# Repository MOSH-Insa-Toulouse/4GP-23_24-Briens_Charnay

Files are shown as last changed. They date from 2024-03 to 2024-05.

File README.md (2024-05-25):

# 4GP-23_24-Briens_Charnay

Projet réalisé sur l'année universitaire 2023/2024 de la formation 4GP, dans le cadre de l'Unité de Formation (UF) "du capteur au banc de test".
Le ci-présent fichier README donne tous les éléments de compréhension du projet global, ainsi que de toutes ses composantes. Cela est réalisé de sorte à permettre à l'utilisateur de reprendre tous les fichiers du présent dépôt GitHub, et de s'en servir.

## Sommaire

 - [Introduction](#introduction)
 - [Capteur à base de crayon graphite](#capteur-graphite)
 - [Circuit Electronique Analogique](#circuit-electronique-analogique)
 - [Kicad : réalisation du shield électronique PCB](#kicad)
 - [Banc de test](#banc-de-test)
 - [Interface Homme-Machine](#ihm)
 - [Programmation](#programmation)
 - [Datasheet](#datasheet)
***
## Introduction
### Contexte du projet

Nos travaux se sont basés sur les résultats d'une publication scientifique \[Cheng-Wei Lin et al., 2014]. Celle-ci étudiait l'utilisation de pistes de graphites sur des feuilles de papier comme capteurs de déformation, et donc de contrainte. Une telle technologie aurait de nombreux avantages :
 - Elle est sobre ;
 - Elle consomme peu d'énergie ;
 - Elle est simple d'utilisation ;
 - Elle est facilement réparable et remplaçable avec peu de ressources ;
 - Les ressources nécessaires sont disponibles au grand public pour un prix très réduit.

Du point de vue physique, la technologie se base sur les effets granulaires des couches de graphite déposées sur le papier : qui agissent comme des îlots conducteurs, séparés par une absence de graphite - non conductrice. Cela induit d'infimes capacités en très grand nombre. Lorsque le papier est déformé, la distance entre ces îlots varie, les capacités également. Cela se mesure sur la résistance du dispositif : dont l'évolution angulaire absolue varie linéairement.

### Contenu du projet

Comme annoncé par le nom de l'UF, notre projet a inclut toutes les étapes allant du capteur au bac de test, le tout en open source hardware. Les différentes phases clés du projet ont donc été, telles qu'annoncées en sommaire :
- le développement du capteur à jauge de contrainte à base de crayon graphite ;
- la conception d'un circuit analogique pour interfacer le capteur à jauge de contrainte;
- la programmation arduino de microcontrôleurs ;
- la réalisation d'une application android ;
- la réalisation d'un shield électronique PCB dédié à l'interface du capteur de contrainte ;
- la réalisation d'un banc de test.

Ces différentes étapes ne seront pas présentées dans un ordre temporel mais logique : de sorte à permettre pour chacune de comprendre l'intégralité des éléments.
***
## Capteur graphite
Le capteur graphite développé se présente sous la forme suivante, toutes les grandeurs sont données en mm :



On note le signal prévu pour chacun des pins :
- pin 1 : +5V
- pin 2 : sortie analogique
Les deux pins sont inversibles.

Les zones pointillées doivent être recouverte d'une épaisse couche de graphite, déposée par crayon.
Les pins utilisés sont supposés classiques, comme par exemple des pinces métalliques.
***
## Circuit Electronique Analogique

L'impédance de notre capteur graphite est de l'ordre du gigaOhm, les courants et les variations de courant à mesurer seront donc très faible. Afin que l'entrée convertisseur analogique numérique de l'arduino puisse détecter ces variations de tension, nous avons dû réaliser un circuit d'amplification. Nous avons choisi un montage transimpédance à deux étages en utilisant l'amplificateur opérationnel LTC 1050. Ce montage permet de convertir le courant en tension ainsi que de réaliser un gain conséquent. Le montage final, présenté ci-dessous, inclut aussi plusieurs filtres :

- R5 en entrée protège l'ampli opérationnel contre les décharges électrostatiques, en
forme avec C1 un filtre pour les bruits en tension
- C1 avec R1 forme un filtre pour le bruit en courant
- R2 sera interchangeable, pour permettre une adaptation du calibre
- C4 avec R3 forme un filtre actif
- C2 avec R6 forme le filtre de sortie
- C3 filtre le bruit d'alimentation

LT_Spice_simulation_capteur_commentaires

*Fichier associé* : Circuit_capteur_final.asc

***
## Kicad
La réalisation du shield électronique PCB nous avons utilisé le logiciel Kicad 8.0.

### Schematic

La première étape a été de réaliser le schematic du circuit electronique analogique en implantant les différents composants que nous avons vu dans la partie cirtuit electronique analogique. Nous avons uniquement remplacé le résistance R2 par le potentiomètre digital MCP-41050. Cela nous permet de faire varier la résistance R2 et donc d'avoir la possibilité de jouer sur le gain de l'amplificateur.

Nous avons ajouté plusieurs composants :

- Le capteur graphite
- Un capteur flex dans le but de le comparer avec notre solution lowtech
- Un écran OLED afin d'afficher les valeurs mesurées ainsi que la valeur de résistance du potentiomètre digital.
- Un module bluetooth HC-6 pour pouvoir communiquer avec une application Android
- Des boutons qui permettrons de se déplacer dans le menu et de selectionner un champ
- Le shield pour connecter l'arduino
- Un filtre passif pour les bruits venant de l'alimentation

Kicad_schematic

*Fichier associé* : Shield_capteur.kicad_sch

***
### PCB

Nous avons ensuite pu implanter les différents composants sur le PCB comme présenté ci-dessous.

Kicad_pcb

Les dimensionnements sont les suivants :
- La largeur des pistes est de 0,8mm
- Les pads circulaires pour les composants ont un diamètre de 2,54mm avec un trou circulaire de 0,8mm
- Les pads ovoïde pour les raccordements par pins ont une largeur de 2mm et une longueur de 2,54mm. Les pins de raccordements pour l'arduino nécessite un trou de 1mm de diamètre. Les pads pour les supports de plaques ont quand à eux un trou de 0,8mm

  Le plan de masse a été généré automatiquement par Kicad. En effectuant le test de vérification des règles de dessin, nous avons pu corriger des erreurs de placement ou de superposition des composants.
L'organisation de notre PCB nous a permis de ne pas avoir besoin de créer des VIAs. Nous avons ensuite pu imprimer le masque de notre circuit afin de réaliser le shield par voie chimique.

*Fichier associé* : Shield_capteur.kicad_pcb

***
## Banc de test

Afin de réaliser des mesures précises et reproductibles, nous avons réalisé un banc de test complet. Celui-ci est composé de différents composants présentés ci-dessous :

Banc_de_test

Comme présenté sur la photo détaillée, nous avons utilisé un second arduino pour réaliser notre banc de test. Ce dernier contrôle le servomoteur qui permet l'enroulement d'un cable autour d'une poulie. Cela permet de plier d'un pas choisi, de manière très contrôlé et reproductible le capteur graphite. Ce second arduino est branché sur les pins l'arduino principal afin qu'une synchronisation entre les changements de degrés et la mesure puisse s'effectuer. Vous trouverez plus de détails sur la communication entre les deux arduino dans la partie programmation. 

***
## IHM
L'Interface Homme-Machine (ou IHM) correspond à tous les éléments permettant la communication entre l'utilisateur et les composants software.
### Boutons et écran OLED
Trois boutons ainsi qu'un écran OLED sont directement présents sur le shield :



Du haut vers le bas, les trois boutons correspondent aux actions :
- select ;
- up ;
- down.

L'écran OLED affiche un total de 4 champs. Les deux premiers sont modifiables, les deux derniers correspondent à des mesures réalisées.
- la valeur du potentiomètre digital ;
- l'unité de mesure ;
- la valeur mesurée dans cette unité par le capteur graphite ;
- la valeur mesurée dans cette unité par le Flex Sensor, capteur commercial.

L'utilisateur contrôle un curseur, celui-ci a deux états disponibles : "- xyz -" et "< xyz >". Le premier correspond au choix du champ à modifier : il permet à l'utilisateur de choisir s'il souhait modifier la valeur du potentiomètre ou l'unité de mesure. Le deuxième correspond à la modification du champ actuel : les boutons up et down permettent alors de se déplacer parmis les différentes options proposées pour le champ actuel. La pression du bouton select permet de passer d'un état à l'autre.
### Application Android
Il est également possible de communiquer avec l'arduino via une application android connectée en bluetooth. Celle-ci se présente ainsi :



Chaque ligne possède un rôle :
- la première, "Bluetooth et fichier" : permet de se connecter à l'arduino en bluetooth, de s'en déconnecter, et d'exporter les données du graphe. L'export se fait dans un fichier texte généré dans le téléphone ;
- la deuxième, "Contrôle d'acquisition" : permet de lancer l'acquisition de données, de la stopper, ou de lancer un test automatisé de la jauge (voir banc de test) ;
- la troisième est le graphe sur lequel apparaissent les données récoltées ;
- la quatrième, "Contrôle graphique" : permet de remettre le graphique à zéro, et de changer l'unité de mesure en volts, en ohms, ou en degrés ;
- la cinquième, "Nombre de points" : permet de choisir le nombre de point maximum à enregistrer et afficher sur le graphique.

*Fichiers associés* :
- application android/AppMOSH1.apk
- application android/CodeAppAndroid.aia
***
## Programmation
### Protocoles de communication
Au sein de notre projet, nous avons mis en place deux protocoles de communication : entre le téléphone et l'arduino du capteur graphite (bluetooth), ainsi qu'entre cette dernière et l'arduino du banc de test (électronique directe).
#### Communication Bluetooth
Dans le cadre de la communication bluetooth entre le téléphone et l'arduino du capteur graphite, les données sont transmises sous format ASCII, par des messages de 16 caractères, sous le format suivent :



Le téléphone est maître de la communication, l'arduino joue le rôle d'esclave. Le caractère "commande" permet de transmettre une information ou ordre spécifique, nous notons les différentes possibilités :

Du téléphone vers l'arduino :
- d : demander l'envoie d'un message ;
- V : choix d'une mesure en volts ;
- O : choix d'une mesure en ohms ;
- D : choix d'une mesure en degrés ;
- t : lancement d'un test automatisé.

De l'arduino vers le téléphone :
- V : message contenant une donnée en volts ;
- O : message contenant une donnée en ohms ;
- D : message contenant une donnée en degrés ;
- c : information du lancement d'un test automatisé ;
- f : information de la fin d'un test automatisé.
#### Communication électronique directe
Dans le cadre de la communication électronique directe entre les arduinos du capteur graphite et du banc de test, deux lignes de communication sont utilisées : chacune contrôlée par une carte arduino. Ce protocole de communication permet de synchroniser le lancement des tests automatisés entre le banc de test, et l'enregistrement des mesures sur le téléphone. Le chronogramme se présente ainsi :



Nous détaillons chaque évolution :
- état initial : les deux lignes sont à l'état down ;
- l'arduino du capteur reçoit l'ordre de l'application de lancer le test automatisé, sa ligne passe à up ;
- l'arduino du banc de test lit l'information, lance le test, et passe sa ligne à up ;
- l'arduino du capteur lit que le test a bien été lancé, passe sa ligne à down, et envoie l'information à l'application ;
- une fois le test terminé, l'arduino du banc de test passe sa ligne à down ;
- l'arduino du capteur lit que le test est terminé, et envoie l'information à l'application.
### Programme Arduino
Deux programmes arduinos ont été créés, pour les deux cartes utilisées dans ce projet : celle du shield PCB (connectée au capteur graphite), et celle du banc de test. Nous détaillons leur fonctionnement.
#### Arduino du capteur graphite
Le fonctionnement général de l'arduino du capteur graphite suit la logique présentée dans le schéma suivant :



Le choix a été fait de réaliser un debouncing des boutons entièrement software.

*Fichier associé* : programme_complet/programme_complet.ino
#### Arduino du banc de test
L'arduino du banc de test possède un programme bien plus simple et direct. Celui-ci suit la structure suivante :
- ajuster la position du Servomoteur : à 0 si aucun test n'est en cours, sinon une autre valeur variable ;
- lire et écrire sur les lignes de communication avec l'arduino du capteur graphite.

*Fichier associé* : programme_second_arduino/prog_second_arduino/prog_second_arduino.ino
***
## Datasheet
Finalement, la combinaison de tous ces éléments a permis la récolte de données, et la rédaction d'une datasheet complète du capteur graphite. Celle-ci est divisée en plusieurs catégories :
- Caractéristiques générales : points clés à l'avantage du capteur ;
- Description : description de la physique du fonctionnement du capteur, développement de ses avantages clés, objectif du développement du capteur ;
- Description des pins : description des pins et signaux du capteur, permettant son implémentation électronique ;
- Dimensions : description matérielle du capteur ;
- Spécifications : description technique concise du capteur ;
- Conditions d'utilisation standard : conditions environnementales classiques, pour lesquelles le capteur a été développé ;
- Caractéristiques électriques : pour les différentes variantes du capteur (en fonction du crayon utilisé), évolution de la résistance absolue et relative en fonction de l'angle ;
- Utilisation typique : exemple d'un circuit électronique typique dans lequel implémenter le capteur pour en tirer des données.
Ce circuit électronique typique correspond à celui que nous avons réalisé sur l'arduino du capteur, et présenté précédemment.

Cette datasheet permet à tout nouvel arrivant de produire et d'utiliser notre capteur graphite : dans un esprit Low-Tech et Open Source.

*Fichier associé* : Datasheet_strain_gauge-MCharnay-ABriens.pdf

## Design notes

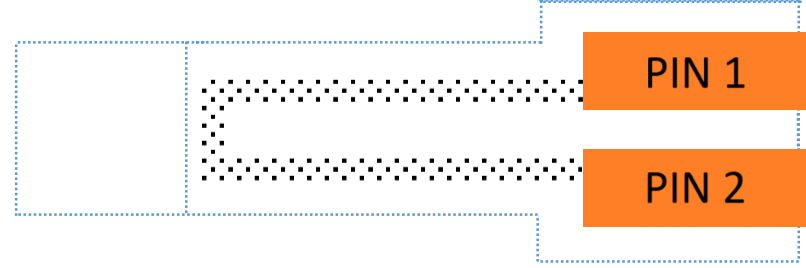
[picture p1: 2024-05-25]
Image_capteur_pins.png

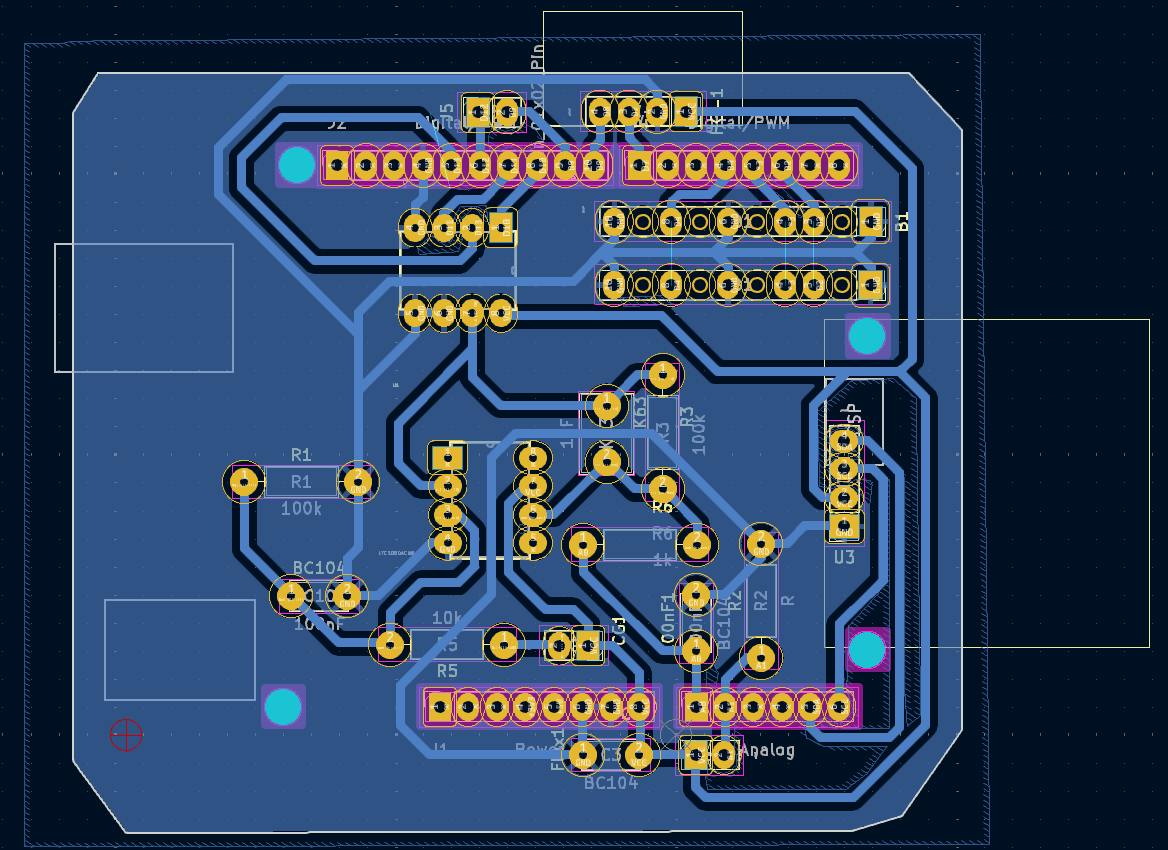
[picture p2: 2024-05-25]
Kicad_pcb.png

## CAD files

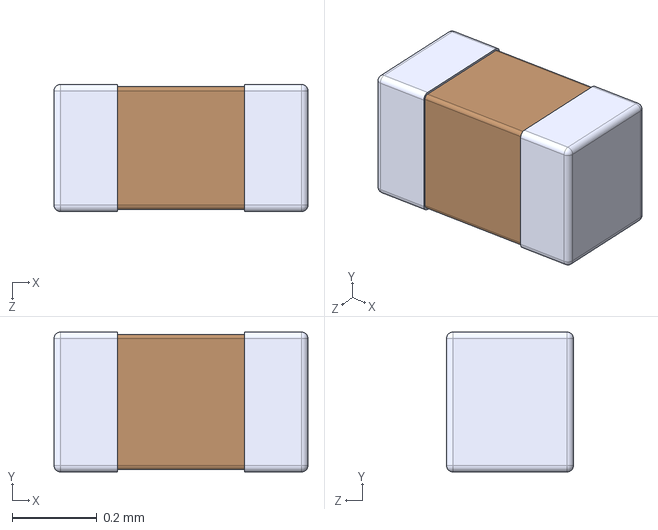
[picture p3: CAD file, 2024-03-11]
BC104_symbol/GRM033B31A104KE84D.step
0.6 x 0.33 x 0.3 mm

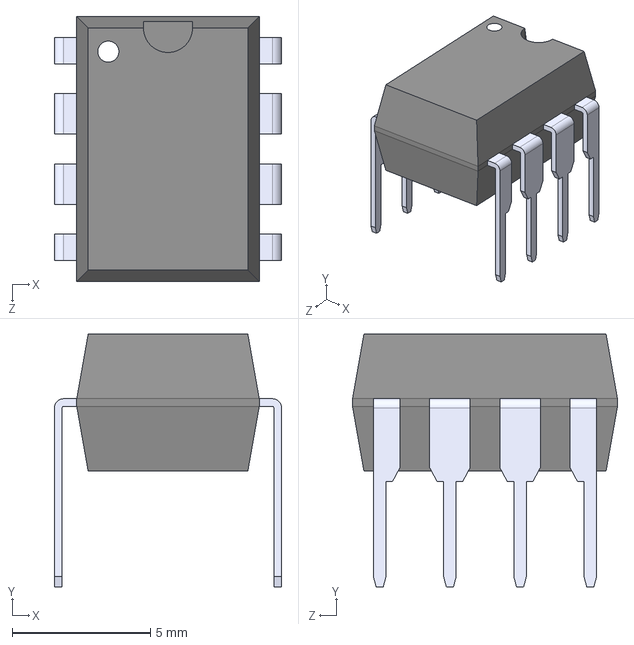
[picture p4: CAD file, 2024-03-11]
LTC1050ACN8_PBF/LTC1050ACN8_PBF.step
8.22 x 9.14 x 9.59 mm

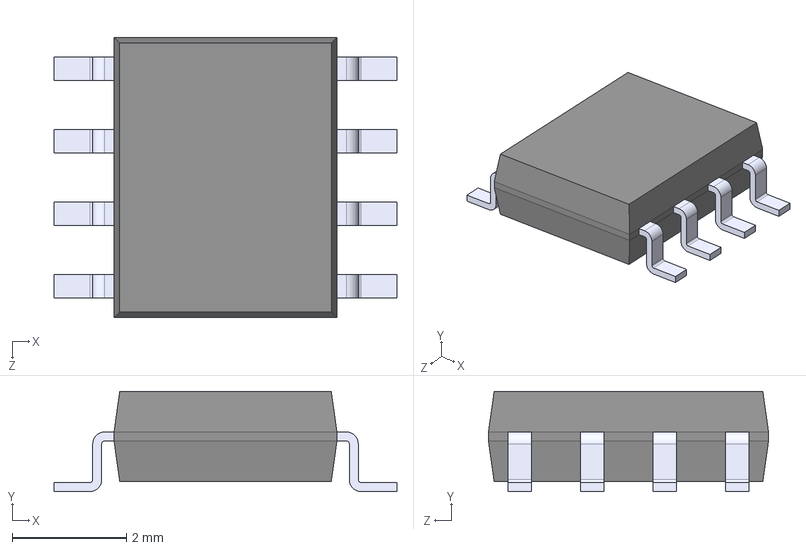
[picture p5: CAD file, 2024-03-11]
MCP4131-103E_SN/MCP4131-103E_SN.step
6.00 x 1.75 x 4.90 mm

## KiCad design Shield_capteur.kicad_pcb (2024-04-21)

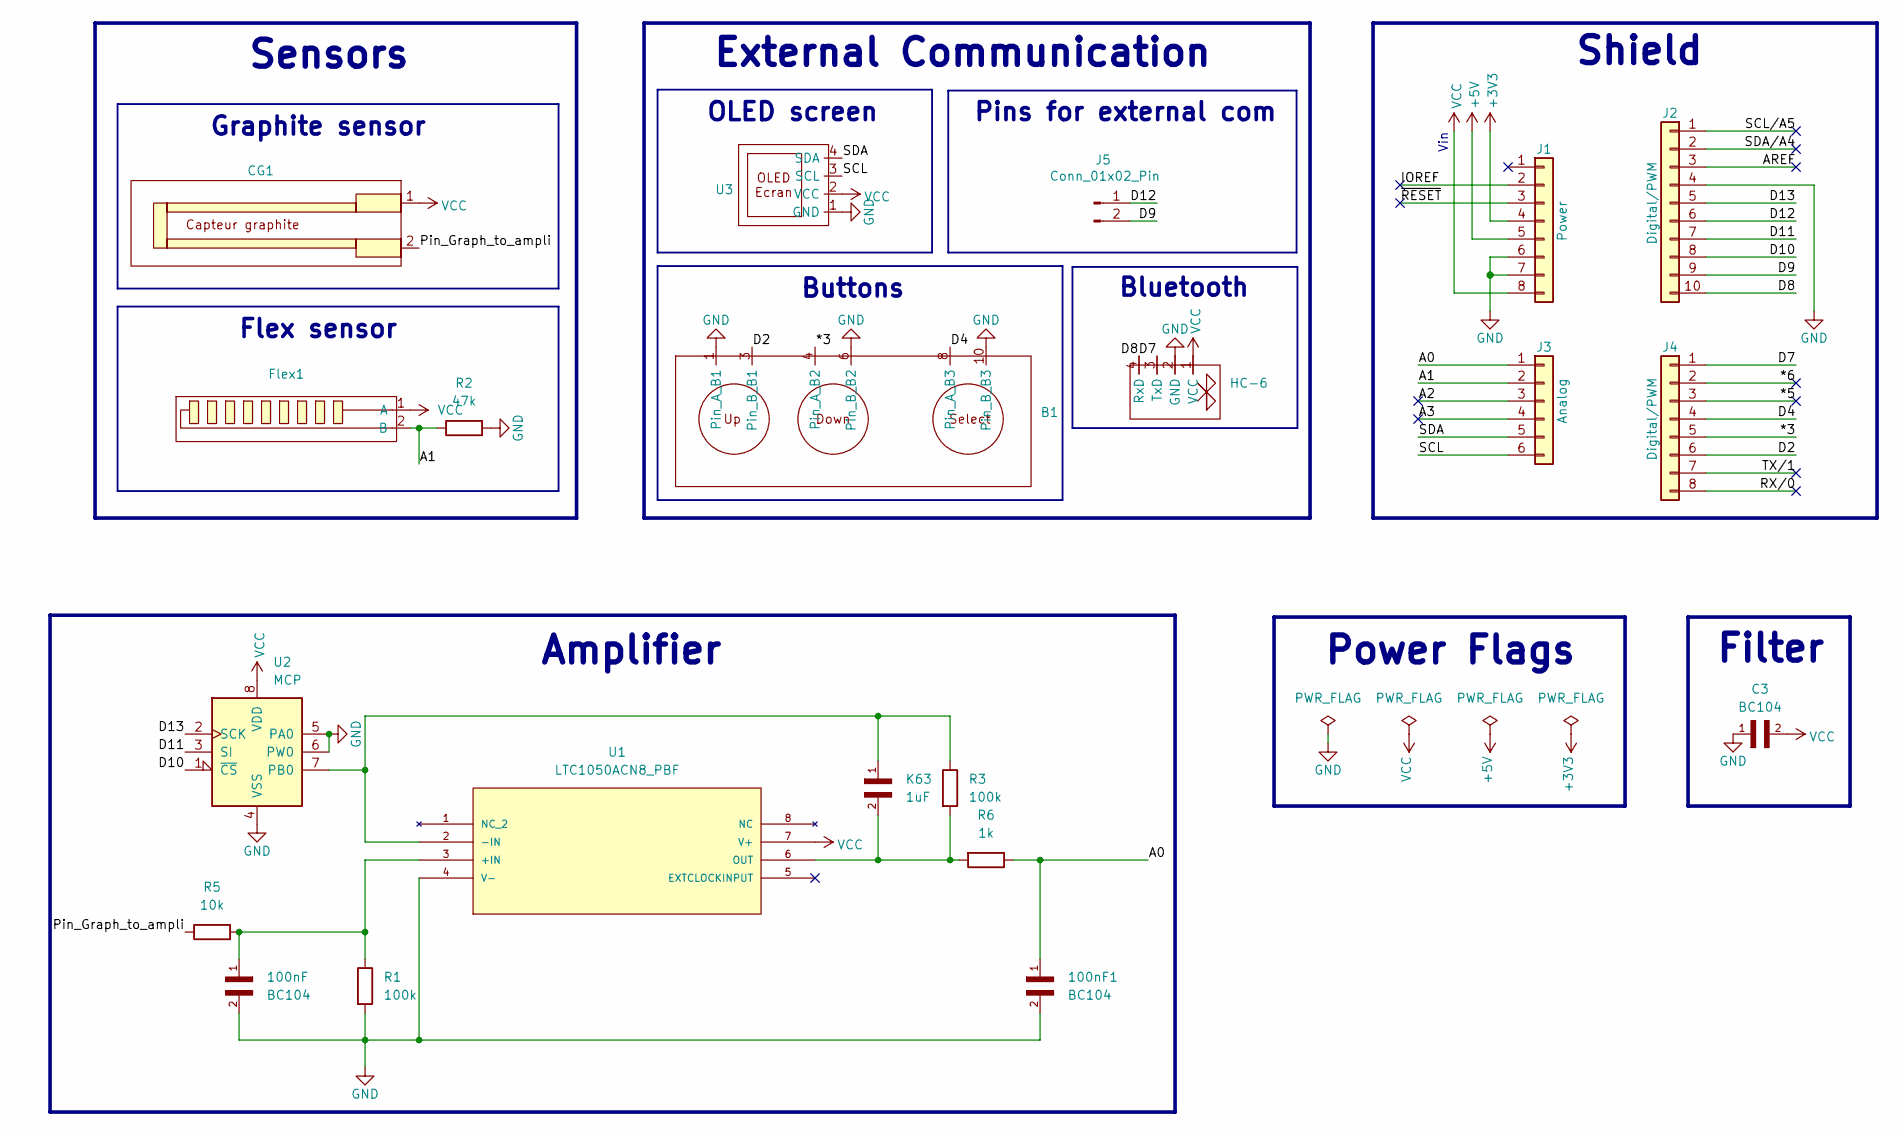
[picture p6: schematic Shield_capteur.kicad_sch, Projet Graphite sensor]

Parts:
100nF1: BC104; C_Disc_D5.0mm_W2.5mm_P5.00mm
B1: Boutons_x3
BC104: 100nF; C_Disc_D5.0mm_W2.5mm_P5.00mm
C3: BC104; C_Disc_D5.0mm_W2.5mm_P5.00mm
CG1: PinSocket_1x02_P2.54mm_Vertical
Flex1: PinSocket_1x02_P2.54mm_Vertical
HC-6: PinSocket_1x04_P2.54mm_Vertical
J1: Power; PinSocket_1x08_P2.54mm_Vertical
J2: Digital/PWM; PinSocket_1x10_P2.54mm_Vertical
J3: Analog; PinSocket_1x06_P2.54mm_Vertical
J4: Digital/PWM; PinSocket_1x08_P2.54mm_Vertical
J5: Conn_01x02_Pin; PinSocket_1x02_P2.54mm_Vertical
K63: 1uF; C_Rect_L7.0mm_W4.5mm_P5.00mm
R1, R3: 100k; R_Axial_DIN0207_L6.3mm_D2.5mm_P10.16mm_Horizontal
R2: 47k; R_Axial_DIN0207_L6.3mm_D2.5mm_P10.16mm_Horizontal
R5: 10k; R_Axial_DIN0207_L6.3mm_D2.5mm_P10.16mm_Horizontal
R6: 1k; R_Axial_DIN0207_L6.3mm_D2.5mm_P10.16mm_Horizontal
U1: LTC1050ACN8_PBF; PDIP-8_N; MANUFACTURER_PART_NUMBER ltc1050acn8
U2: MCP; PDIP-8_N
U3: PinSocket_1x04_P2.54mm_Vertical

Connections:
+3V3: J1.4
+5V: J1.5
/*3: B1.4 (Pin_A_B2), J4.5
/*5: J4.3
/*6: J4.2
/A0: 100nF1.1, J3.1, R6.1
/A1: Flex1.2 (B), J3.2, R2.1
/A2: J3.3
/A3: J3.4
/AREF: J2.3
/D2: B1.3 (Pin_B_B1), J4.6
/D4: B1.8 (Pin_A_B3), J4.4
/D7: HC-6.3 (TxD), J4.1; also elsewhere on the board
/D8: HC-6.4 (RxD), J2.10; also elsewhere on the board
/D9: J2.9, J5.2
/D10: J2.8, U2.1 (~CS)
/D11: J2.7, U2.3 (SI)
/D12: J2.6, J5.1
/D13: J2.5, U2.2 (SCK)
/IOREF: J1.2
/RX/0: J4.8
/SCL: J3.6, U3.3 (SCL)
/SCL/A5: J2.1
/SDA: J3.5, U3.4 (SDA)
/SDA/A4: J2.2
/TX/1: J4.7
/~RESET: J1.3
GND: 100nF1.2, B1.1 (Pin_A_B1), B1.6 (Pin_B_B2), B1.10 (Pin_B_B3), BC104.2, C3.1, HC-6.2 (GND), J1.6, J1.7, J2.4, R1.2, R2.2, U1.4 (V-), U2.4 (VSS), U2.5 (PA0), U2.6 (PW0), U3.1 (GND); also elsewhere on the board
unnamed: CG1.2, R5.1
unnamed: BC104.1, R1.1, R5.2, U1.3 (+IN)
unnamed: K63.1, R3.1, U1.2 (-IN), U2.7 (PB0)
unnamed: K63.2, R3.2, R6.2, U1.6 (OUT)
VCC: C3.2, CG1.1, Flex1.1 (A), HC-6.1 (VCC), J1.8, U1.7 (V+), U2.8 (VDD), U3.2 (VCC); also elsewhere on the board

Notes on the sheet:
Graphite sensor
Vin
Amplifier
Flex sensor
Filter
Power Flags
Pins for external com
Bluetooth
Shield
Sensors
OLED screen
External Communication
Buttons

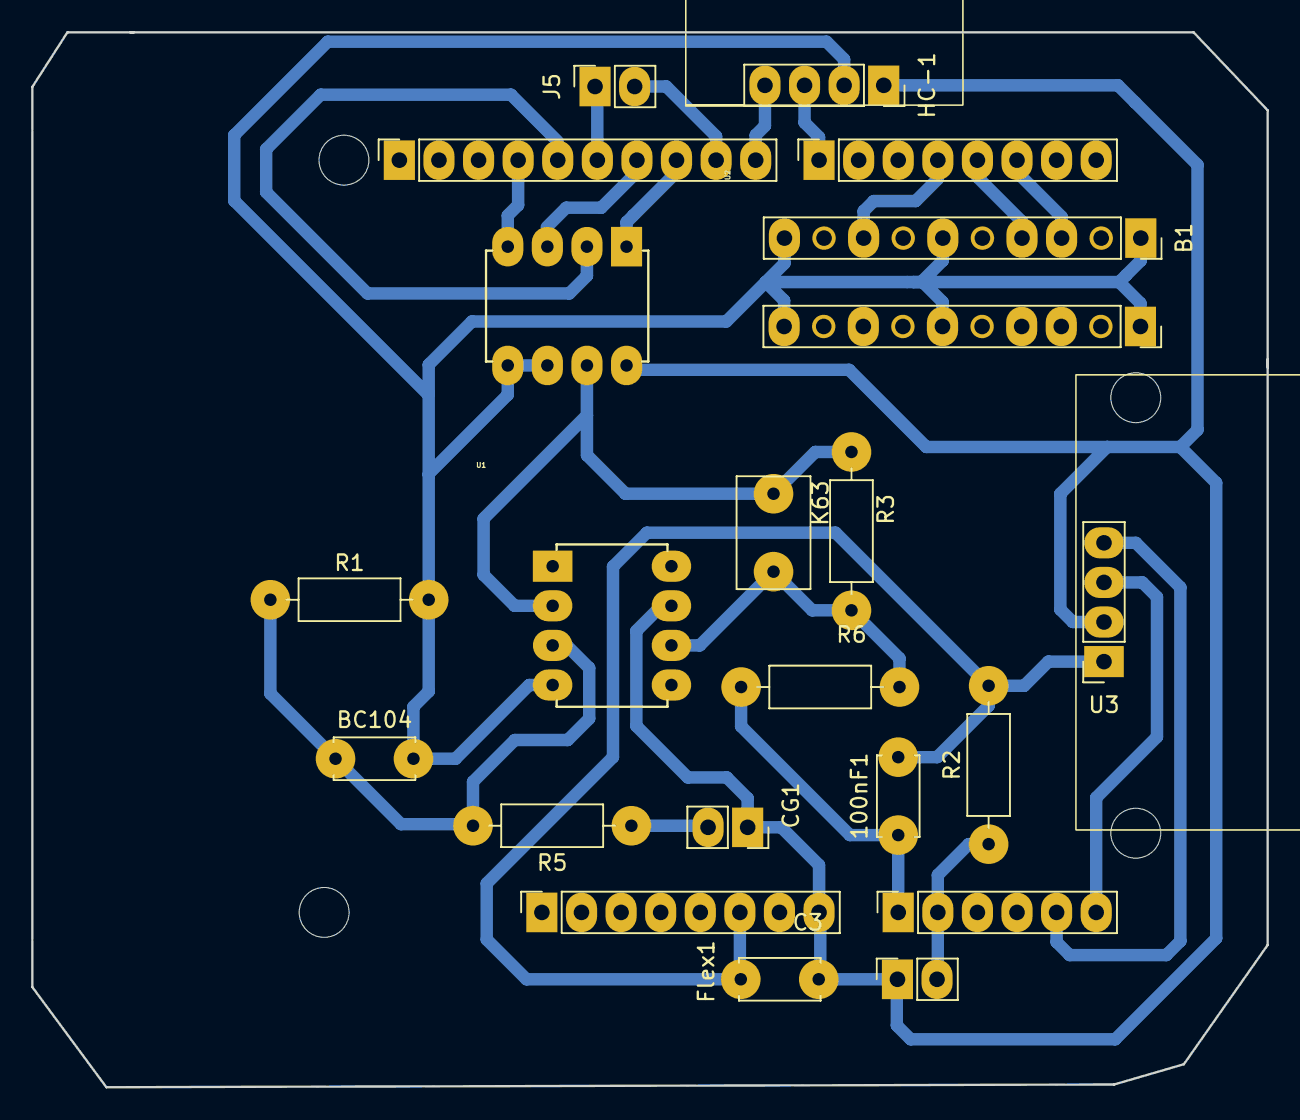
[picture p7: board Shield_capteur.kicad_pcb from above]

Board: 2 copper layers, 79.2 x 67.7 mm, 25 parts (0 on the bottom side), 20 nets.

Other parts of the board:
HC-1: PinSocket_1x04_P2.54mm_Vertical
MH1, MH2, MH3, MH4: MountingHole_3.2mm

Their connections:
/D7: HC-1.3 (TxD); also elsewhere on the board
/D8: HC-1.4 (RxD); also elsewhere on the board
GND: HC-1.2 (GND); also elsewhere on the board
VCC: HC-1.1 (VCC); also elsewhere on the board

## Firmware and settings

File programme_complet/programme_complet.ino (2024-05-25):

#include <SoftwareSerial.h>
#include <Adafruit_SSD1306.h>
#include <SPI.h>
//#include <Servo.h>

//#define pinServo 2
//Servo myservo;

#define flexPin A1
#define flexR_DIV 39000
#define flexflatResistance 25000
#define flexbendResistance 100000

#define bluetoothRxPin 7
#define bluetoothTxPin 8
#define baudrate 9600
#define sizeBuffer 16
SoftwareSerial mySerial(bluetoothRxPin,bluetoothTxPin);
char bufferBluetoothOutput[sizeBuffer]={0};
char bufferBluetoothInput[sizeBuffer]={0};

#define ampliPin A0

#define upButton 3
uint8_t upState;
uint8_t lastUpState=1;
long upTimer;
#define downButton 2
uint8_t downState;
uint8_t lastDownState=1;
long downTimer;
#define selectButton 4
uint8_t selectState;
uint8_t lastSelectState=1;
long selectTimer;
#define debounceDelay 50

#define nombreDePixelsEnLargeur 128         // Taille de l'écran OLED, en pixel, au niveau de sa largeur
#define nombreDePixelsEnHauteur 64          // Taille de l'écran OLED, en pixel, au niveau de sa hauteur
#define brocheResetOLED         -1
#define adresseI2CecranOLED     0x3C
Adafruit_SSD1306 ecranOLED(nombreDePixelsEnLargeur, nombreDePixelsEnHauteur, &Wire, brocheResetOLED);

#define nbOptionsPotar 12
#define nbOptionsUnite 3
const uint32_t tabChoixPotar[nbOptionsPotar]={125,330,730,1130,1930,2530,5100,10020,19920,30600,40600,50300};
uint8_t choixPotar=0;
uint8_t choixUnite=0;
uint8_t positionMenu=0;
uint8_t selection=0;

#define MCP_NOP 0b000000000
#define MCP_WRITE 0b00010001
#define MCP_SHTDWN 0b00100001

const uint8_t ssMCPin = 10;
const int adresseChoixPotar[nbOptionsPotar]={0,1,3,5,9,12,25,50,100,155,205,255};

const uint8_t VCC=5;

#define syncTxPin 12
#define syncRxPin 9
uint8_t syncTx=0;
uint8_t pastRx=0;
uint8_t syncRx=0;

void setup() {
  Serial.begin(baudrate);

  //~~ Flex Sensor ~~//
  pinMode(flexPin,INPUT);

  //~~ Ampli - capteur graphite ~~//
  pinMode(ampliPin,INPUT);

  //~~ Bluetooth ~~//
  pinMode(bluetoothRxPin,INPUT);
  pinMode(bluetoothTxPin,OUTPUT);
  mySerial.begin(baudrate);
  bufferBluetoothOutput[0]='\0';
  bufferBluetoothOutput[sizeBuffer-1]='\0';

  //~~ Boutons ~~//
  pinMode(upButton,INPUT_PULLUP);
  pinMode(downButton,INPUT_PULLUP);
  pinMode(selectButton,INPUT_PULLUP);

  //~~ OLED ~~//
  ecranOLED.begin(SSD1306_SWITCHCAPVCC, adresseI2CecranOLED);

  //~~ Potar digital ~~//
  pinMode(ssMCPin,OUTPUT);
  digitalWrite(ssMCPin,HIGH);
  SPI.begin();

  //~~ Test automatisé ~~//
  pinMode(syncTxPin,OUTPUT);
  pinMode(syncRxPin,INPUT);
}

void loop() {
  //if(choixPotar==4){choixPotar=3;}
  //else{choixPotar=4;}

   //~~~~~~~~~~~~~~~~ Flex Sensor ~~~~~~~~~~~~~~~~//
  int flexVolt=analogRead(flexPin);
  if(flexVolt==0)flexVolt=1;//eviter division par 0 dans la formule suivante
  float flexRes=flexR_DIV*(1023.0/flexVolt-1.0);
  float flexAngle=map(flexRes,flexflatResistance,flexbendResistance,0,90.0);

  //Serial.println("Cadeau, res : "+String(flexRes)+" ; angle : "+String(flexAngle)+"°.");
  
  //~~~~~~~~~~~~~~~~ Ampli - capteur graphite ~~~~~~~~~~~~~~~~//
  int ampliVolt=analogRead(ampliPin);

  //~~~~~~~~~~~~~~~~ Bluetooth ~~~~~~~~~~~~~~~~//
  commBluetooth(bufferBluetoothOutput,bufferBluetoothInput);
  if(bufferBluetoothInput[0]=='d'){//si l'app envoie une demande de "data"
    char unit='V';
    if(choixUnite==1)unit='O';
    if(choixUnite==2)unit='D';
    //un message composé de l'unité et de la mesure est envoyé
    sendMsg(unit,conversionMesure(ampliVolt),4);
  }
  if(bufferBluetoothInput[0]=='V'){
    choixUnite=0;
  }
  if(bufferBluetoothInput[0]=='O'){
    choixUnite=1;
  }
  if(bufferBluetoothInput[0]=='D'){
    choixUnite=2;
  }
  if(bufferBluetoothInput[0]=='t'){
    syncTx=1;
  }
  bufferBluetoothInput[0]='\0';
  
  //~~~~~~~~~~~~~~~~ Boutons ~~~~~~~~~~~~~~~~//
  debouncingButtons();

  //~~~~~~~~~~~~~~~~ OLED ~~~~~~~~~~~~~~~~//
  updateOLED(conversionMesure(ampliVolt),choixMesureFlex(flexVolt,flexRes,flexAngle));
  //Serial.println(ampliVolt);
  /*Serial.print(F("Potentiometre(0-4) : "));
  Serial.print(choixPotar);
  Serial.print(F(" ; Unite(0-2) : "));
  Serial.println(choixUnite);
  Serial.print(F(" ; selection(V/F) : "));
  Serial.print(selection);
  Serial.print(F(" ; positionMenu(0-2) : "));
  Serial.println(positionMenu);*/
  
  //~~~~~~~~~~~~~~~~ Potentiometre digital ~~~~~~~~~~~~~~~~//
  updatePotar();

  //~~~~~~~~~~~~~~~~ Test automatisé ~~~~~~~~~~~~~~~~//
  syncTest();

  //delay(20);
}

void debouncingButtons()
{
  int readUp=digitalRead(upButton);
  int readDown=digitalRead(downButton);
  int readSelect=digitalRead(selectButton);

  if(readUp!=lastUpState){
    upTimer=millis();
    //Serial.println("ici : "+String(millis()));
  }
  if((millis()-upTimer)>debounceDelay){
    if((upState!=readUp)&&!readUp){
      upButtonAction();
      //Serial.println("ACTION UP : "+String(millis()));
    }
    upState=readUp;
  }
  lastUpState=readUp;

  if(readDown!=lastDownState){
    downTimer=millis();
  }
  if((millis()-downTimer)>debounceDelay){
    if((downState!=readDown)&&!readDown){
      downButtonAction();
      //Serial.println("ACTION DOWN : "+String(millis()));
    }
    downState=readDown;
  }
  lastDownState=readDown;

  if(readSelect!=lastSelectState){
    selectTimer=millis();
  }
  if((millis()-selectTimer)>debounceDelay){
    if((selectState!=readSelect)&&!readSelect){
      selectButtonAction();
      //Serial.println("ACTION SELECT : "+String(millis()));
    }
    selectState=readSelect;
  }
  lastSelectState=readSelect;
}

void upButtonAction()
{
  if(selection==0){
    positionMenu=(positionMenu-1+3)%3;
  }
  else{
    if(positionMenu==1){
      choixPotar=(choixPotar+1)%nbOptionsPotar;
    }
    if(positionMenu==2){
      choixUnite=(choixUnite+1)%nbOptionsUnite;
    }
  }
}

void downButtonAction()
{
  if(selection==0){
    positionMenu=(positionMenu+1)%3;
  }
  else{
    if(positionMenu==1){
      choixPotar=(choixPotar-1+nbOptionsPotar)%nbOptionsPotar;
    }
    if(positionMenu==2){
      choixUnite=(choixUnite-1+nbOptionsUnite)%nbOptionsUnite;
    }
  }
}

void selectButtonAction()
{
  if(positionMenu!=0)selection=(selection+1)%2;
}

void commBluetooth(char* bufferOutput, char* bufferInput)
{
  int i=0;
  while(mySerial.available()){
    do{
      bufferInput[i++]=(char)mySerial.read();
      delay(3);
    }while(mySerial.available()>0);
    Serial.println(bufferInput);
  }
  if(bufferOutput[0]!='\0'){
    mySerial.println(bufferOutput);
    bufferOutput[0]='\0';
  }
}

void sendMsg(char command,float data,int precision)
{//ATTENTION : cette fonction écrase le buffer output du bluetooth, toute donnée encore en attente sera perdue
  for(int i=1;i<sizeBuffer-1;i++){
    bufferBluetoothOutput[i]='/';
  }
  bufferBluetoothOutput[0]=command;
  char temp[sizeBuffer-1];
  dtostrf(data,0,precision,temp);
  strcpy(&bufferBluetoothOutput[1],temp);//1
  for(int i=1;i<sizeBuffer-1;i++){
    if(bufferBluetoothOutput[i]=='\0')bufferBluetoothOutput[i]='/';
  }
}

void updateOLED(float valeurCapGraph,float valeurFlexSensor)
{
  ecranOLED.clearDisplay();
  ecranOLED.setTextSize(1,1);
  ecranOLED.setCursor(0, 0);
  ecranOLED.setTextColor(SSD1306_WHITE);

  ecranOLED.print(F(" ~ Controle mesure ~\n\n"));
  ecranOLED.print(F("Potentio.:"));
  for(int i=5;i>compteNbCaract(tabChoixPotar[choixPotar]);i--)ecranOLED.print(' ');
  miseEnFormeMenu(1,1);
  ecranOLED.print(tabChoixPotar[choixPotar]);
  miseEnFormeMenu(1,0);
  ecranOLED.print(F(" Ohm"));

  ecranOLED.print(F("Unite : "));
  miseEnFormeMenu(2,1);
  if(choixUnite==0)ecranOLED.print(F("Volt"));
  if(choixUnite==1)ecranOLED.print(F("Ohm"));
  if(choixUnite==2)ecranOLED.print(F("Degre"));
  miseEnFormeMenu(2,2);
  ecranOLED.print(F("\n- - - - - - - - - - -"));
  ecranOLED.print(F("\nMesure :"));
  ecranOLED.print(F("\nCap.Graph. "));
  ecranOLED.print(valeurCapGraph);
  ecranOLED.print(' ');
  if(choixUnite==0)ecranOLED.print('V');
  if(choixUnite==1)ecranOLED.print(F("MO"));
  if(choixUnite==2)ecranOLED.print(F("deg"));
  ecranOLED.print(F("\nFlexCapt.  "));
  ecranOLED.print(valeurFlexSensor);
  ecranOLED.print(' ');
  if(choixUnite==0)ecranOLED.print('V');
  if(choixUnite==1)ecranOLED.print(F("O"));
  if(choixUnite==2)ecranOLED.print(F("deg"));

  ecranOLED.display();
}

void miseEnFormeMenu(int position, int ouverture)
{
  if(position!=positionMenu){
    ecranOLED.print(" ");
  }
  else{
    if(selection==0){
      ecranOLED.print("-");
    }
    else{
      if(ouverture==1){
        ecranOLED.print("<");
      }
      else{
        ecranOLED.print(">");
      }
    }
  }
}

void SPIWrite(uint8_t cmd, uint8_t data, uint8_t ssPin)
{
  SPI.beginTransaction(SPISettings(14000000,MSBFIRST,SPI_MODE0));
  digitalWrite(ssPin,LOW);
  SPI.transfer(cmd);
  SPI.transfer(data);
  digitalWrite(ssPin,HIGH);
  SPI.endTransaction();
}

void updatePotar()
{
  SPIWrite(MCP_WRITE,adresseChoixPotar[choixPotar],ssMCPin);
}

int compteNbCaract(float cible)
{
  uint8_t compte=1;
  uint32_t comparateur=10;
  while(cible>=comparateur){
    compte++;
    comparateur*=10;
  }
  return(compte);
}

float conversionMesure(float mesure)
{
  if(choixUnite==0)return(mesure*5.0/1023.0);
  double resistance=(((1+100000.0/tabChoixPotar[choixPotar])*100000.0*(5.0/mesure))-110000.0);
  if(choixUnite==1)return(resistance/1000000.0);
  if(choixUnite==2)return((resistance-98768)/2475.5);//calcul valide pour un crayon 2B
  return(-1);
}

float choixMesureFlex(float flexVolt, float flexRes, float flexAngle)
{
  if(choixUnite==0){
    return(5.0*flexVolt/1023.0);
  }
  if(choixUnite==1){
    return(flexRes);
  }
  if(choixUnite==2){
    return(flexAngle);
  }
}

void syncTest()
{
  digitalWrite(syncTxPin,syncTx);
  //uint8_t syncRx;
  syncRx=digitalRead(syncRxPin);
  if(((syncTx==1)&&(syncRx==1))&&(pastRx==0)){
    sendMsg('c',0,2);
    syncTx=0;
  }
  if((syncRx==0)&&(pastRx==1)){
    sendMsg('f',0,2);
  }
  pastRx=syncRx;
}

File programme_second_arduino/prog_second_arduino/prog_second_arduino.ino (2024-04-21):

#include <Servo.h>
Servo myservo;

#define pinServo 9
#define nbSteps 25
#define angleMaxServo 120
#define pinTx 11
#define pinRx 12
#define delayPalierMesure 4000

int tableangleservo[nbSteps]={0};
int pasServo=angleMaxServo/(nbSteps-1);
uint8_t indexServo=0;
uint8_t testencours=0;

uint8_t valueTx=0;
uint8_t lastRx=0;
int readRx;

void setup(){
  myservo.attach(pinServo);
  myservo.write(0);
  for(indexServo=0;indexServo<nbSteps;indexServo++) 
  {
    tableangleservo[indexServo]=indexServo*pasServo;
  }
  pinMode(pinTx,OUTPUT);
  pinMode(pinRx,INPUT);
  indexServo=0;
  Serial.begin(9600);
  Serial.println("test");
  //Serial.println(pasServo);
}

void loop() {
  if((testencours==1)&&(indexServo<nbSteps)){
    delay(delayPalierMesure);
    myservo.write(tableangleservo[indexServo]);
    //Serial.println((int)tableangleservo[indexServo]);
    indexServo++;
  }
  else{
    indexServo=0;
    testencours=0;
    myservo.write(0);
  }
  syncTest();
}

void syncTest()
{
  //uint8_t readRx;
  readRx=digitalRead(pinRx);
  Serial.print("Comm : T-R ");
  Serial.print(valueTx);
  Serial.print(' ');
  Serial.println(readRx);
  Serial.print("Actua : i t ");
  Serial.print(indexServo);
  Serial.print(' ');
  Serial.println(testencours);
  if(readRx==1){
    testencours=1;
    valueTx=1;
  }
  if(testencours==0){
    valueTx=0;
  }
  digitalWrite(pinTx,valueTx);
}

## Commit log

2024-03-06 Fichier base shield kicad
    [Shield_capteur.kicad_pcb, Shield_capteur.kicad_sch]
2024-03-06 correction commentaires
    [Shield_capteur.kicad_sch]
2024-03-06 Avancée sur le shield, schéma +footprint
    [GRM033B31A104KE84D.step, LTC1050ACN8_PBF.step, Shield_capteur.kicad_pcb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]
2024-03-11 Progrès TD Datasheet
    [MCP4131-103E_SN.step, Shield_capteur.kicad_pcb, Shield_capteur.kicad_sch]
2024-03-13 Fin de la schematic
    [Shield_capteur.kicad_pcb, Shield_capteur.kicad_sch]
2024-03-13 Changement pastilles PCB
    [Shield_capteur.kicad_pcb]
2024-03-14 Avancé PCB positionnement de tous les composants
    [Shield_capteur.kicad_pcb, Shield_capteur.kicad_sch]
2024-03-16 Fin du placement des composants et pistes sur PCB. Quelques erreurs mineures à régler
    [Shield_capteur.kicad_pcb, Shield_capteur.kicad_sch]
2024-03-18 Correction du PCB il reste connection RFlex
    [Shield_capteur.kicad_pcb, Shield_capteur.kicad_sch]
2024-03-20 Changement de la largeur des pistes de 0.6mm à 0.8mm
    [Shield_capteur.kicad_pcb]
2024-03-20 Ajout programme Arduino
2024-03-21 optimisation memoire et ajout servo (commentaire)
2024-03-22 Ajout lien second Arduino
    [Shield_capteur.kicad_pcb, Shield_capteur.kicad_sch]
2024-03-27 Implantation Arduino avec PCB
2024-04-05 ajout flex sensor sur OLED + implantation controle nb points sur app
    [programme_complet.ino]
2024-04-18 fin kicad ajout liaison second arduino
    [Shield_capteur.kicad_pcb, Shield_capteur.kicad_sch]
2024-04-19 Début du programme pour le second arduino programmation du servomoteur
2024-04-19 Ajout fonctions de synchronisation Arduino
2024-04-19 correction bug synchronisation programme principal
    [programme_complet.ino]
2024-04-19 finalisation synchronisation arduino, mise à jour app & ajout fichier projet app
2024-04-21 Mise en forme shematic et rajout valeurs MCP
    [Shield_capteur.kicad_pcb, Shield_capteur.kicad_sch]
2024-05-25 correction datasheet, ajout arduino calcul angle
    [programme_complet.ino]

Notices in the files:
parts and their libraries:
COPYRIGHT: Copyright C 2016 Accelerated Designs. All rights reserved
